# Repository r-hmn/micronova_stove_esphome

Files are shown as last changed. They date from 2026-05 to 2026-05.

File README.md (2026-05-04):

# micronova_stove_esphome
Three sub-projects for connecting a home automation system to ARTEL IDRO15 PelletStove.
1. Kicad PCB for 'ESP32 mini D1'.
2. Arduino-code for reading all RAM- and EEPROM-registers easily.
3. ESPHOME-yaml for connecting the PelletStove to e.g. Home Assistent or OpenHAB.

## Contained projects:

### 1) Kicad `stove-reader-pcb`
A Kicad project for PCB to fit an 'ESP32 mini D1' to communicate with a PelletStove having a MicroNova compatible serial interface.

The PCB has JST-XH2.54 connectors for
- 2x I2C devices
- 2x external DSB18B20 temperature sensors
- 1x for power conversion
- 1x pelletstove serial

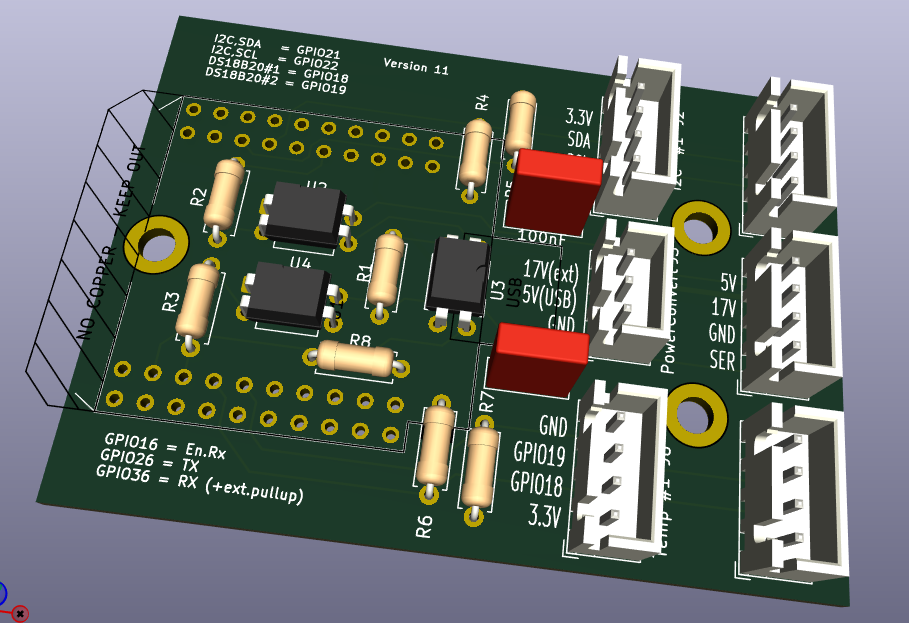
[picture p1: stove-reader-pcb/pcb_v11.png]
PCB


### 2) Arduino `stove-ram-reader`
I created it to find the correct address of the Fume-Temperature address for my stove type.

Works in combination with the PCB.
Code is for ArduinoIDE 2.x to program an 'ESP32 mini D1'.
Program to interrogate the RAM and EEPROM registers and publishes it via its webserver.
Its address is published via mDNS as `esp32.local`
Webserver can be accessed at http://esp32.local/

Uses a version of:
- `micronova_stove.h` code from https://github.com/eni23/micronova-controller
- `micronova_stove.cpp` code from https://github.com/eni23/micronova-controller

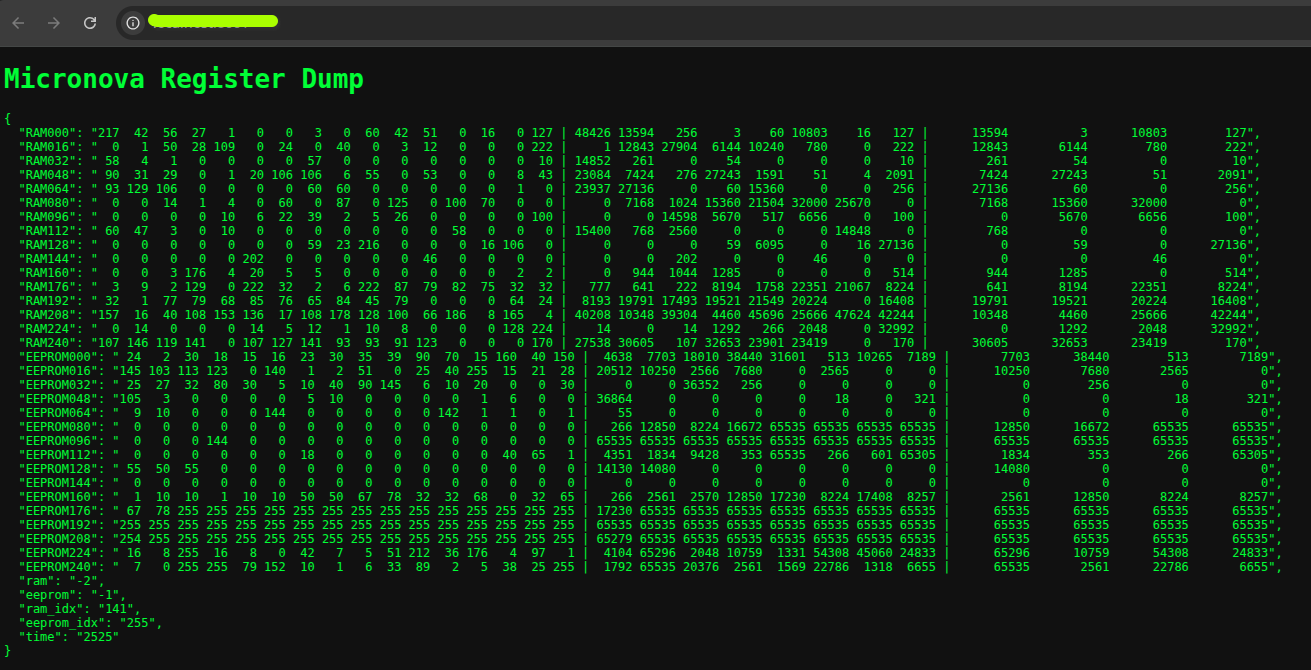
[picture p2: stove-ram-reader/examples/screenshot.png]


### 3) ESPHOME yaml
Works in combination with the PCB.

YAML which interfaces with 
- OLED screen for local readout (i2c OLED 128x32).
- Pellet level sensor (i2c VL53L0X time-of-flight infrared distance sensor).
- External temperature sensors (In below image the DSB18B20's are not connected).

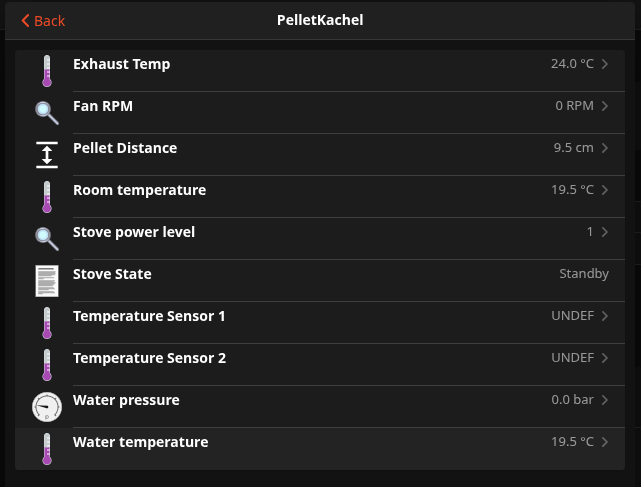
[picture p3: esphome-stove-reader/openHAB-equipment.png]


## Related info:
- https://github.com/eni23/micronova-controller
- https://esphome.io/components/micronova/

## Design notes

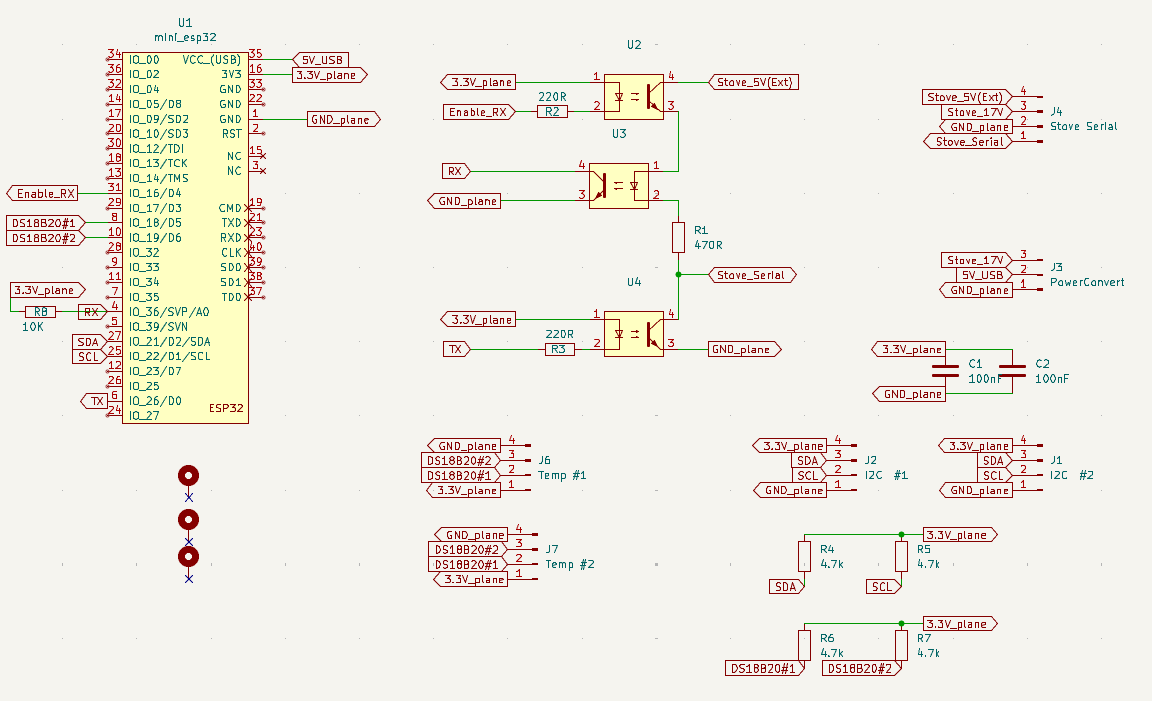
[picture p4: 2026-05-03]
stove-reader-pcb/logic_v11.png

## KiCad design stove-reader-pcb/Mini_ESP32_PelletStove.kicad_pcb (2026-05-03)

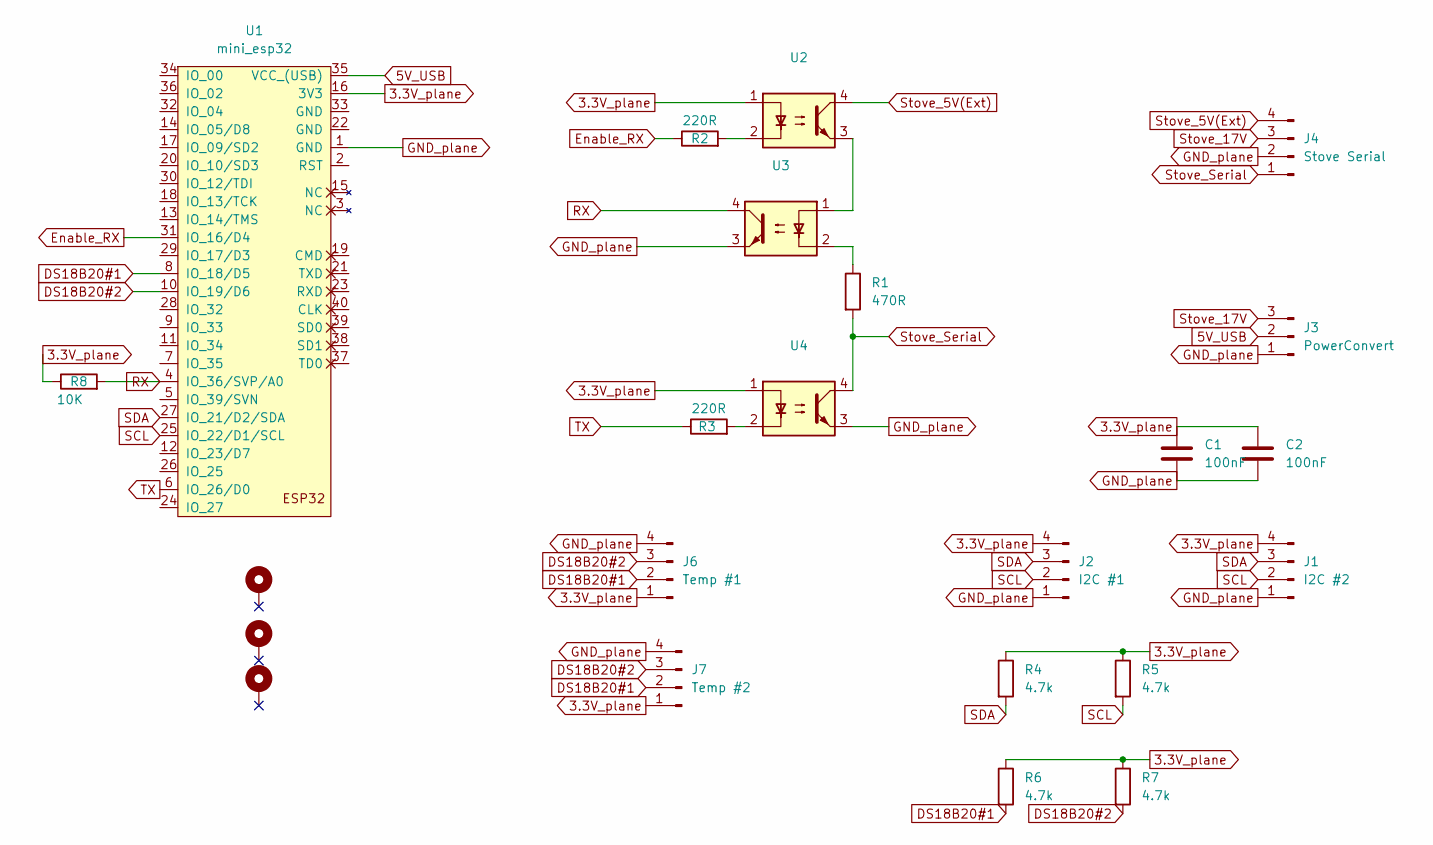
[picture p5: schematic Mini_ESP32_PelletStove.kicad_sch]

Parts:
C1, C2: 100nF; C_Rect_L7.0mm_W2.5mm_P5.00mm
H1, H2, H3: MountingHole_Pad; MountingHole_3.2mm_M3_DIN965_Pad
J1: I2C #2; JST_XH_B4B-XH-A_1x04_P2.50mm_Vertical
J2: I2C #1; JST_XH_B4B-XH-A_1x04_P2.50mm_Vertical
J3: PowerConvert; JST_XH_B3B-XH-A_1x03_P2.50mm_Vertical
J4: Stove Serial; JST_XH_B4B-XH-A_1x04_P2.50mm_Vertical
J6: Temp #1; JST_XH_B4B-XH-A_1x04_P2.50mm_Vertical
J7: Temp #2; JST_XH_B4B-XH-A_1x04_P2.50mm_Vertical
R1: 470R; R_Axial_DIN0207_L6.3mm_D2.5mm_P7.62mm_Horizontal
R2, R3: 220R; R_Axial_DIN0207_L6.3mm_D2.5mm_P7.62mm_Horizontal
R4, R5, R6, R7: 4.7k; R_Axial_DIN0207_L6.3mm_D2.5mm_P7.62mm_Horizontal
R8: 10K; R_Axial_DIN0207_L6.3mm_D2.5mm_P7.62mm_Horizontal
U1: mini_esp32; ESP32_mini-HAT
U2, U3, U4: SFH617A-4X006; DIP-4_W7.62mm

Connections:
3.3V_plane: C1.1, C2.1, J1.4, J2.4, J6.1, J7.1, R4.1, R5.1, R6.1, R7.1, R8.1, U1.16 (3V3), U2.1, U4.1
5V_USB: J3.2, U1.35 (VCC_(USB))
DS18B20#1: J6.2, J7.2, R6.2, U1.8 (IO_18/D5)
DS18B20#2: J6.3, J7.3, R7.2, U1.10 (IO_19/D6)
Enable_RX: R2.1, U1.31 (IO_16/D4)
GND_plane: C1.2, C2.2, J1.1, J2.1, J3.1, J4.2, J6.4, J7.4, U1.1 (GND), U3.3, U4.3
unnamed: R1.1, U3.2
unnamed: R2.2, U2.2
unnamed: R3.2, U4.2
unnamed: U2.3, U3.1
RX: R8.2, U1.4 (IO_36/SVP/A0), U3.4
SCL: J1.2, J2.2, R5.2, U1.25 (IO_22/D1/SCL)
SDA: J1.3, J2.3, R4.2, U1.27 (IO_21/D2/SDA)
Stove_5V(Ext): J4.4, U2.4
Stove_17V: J3.3, J4.3
Stove_Serial: J4.1, R1.2, U4.4
TX: R3.1, U1.6 (IO_26/D0)

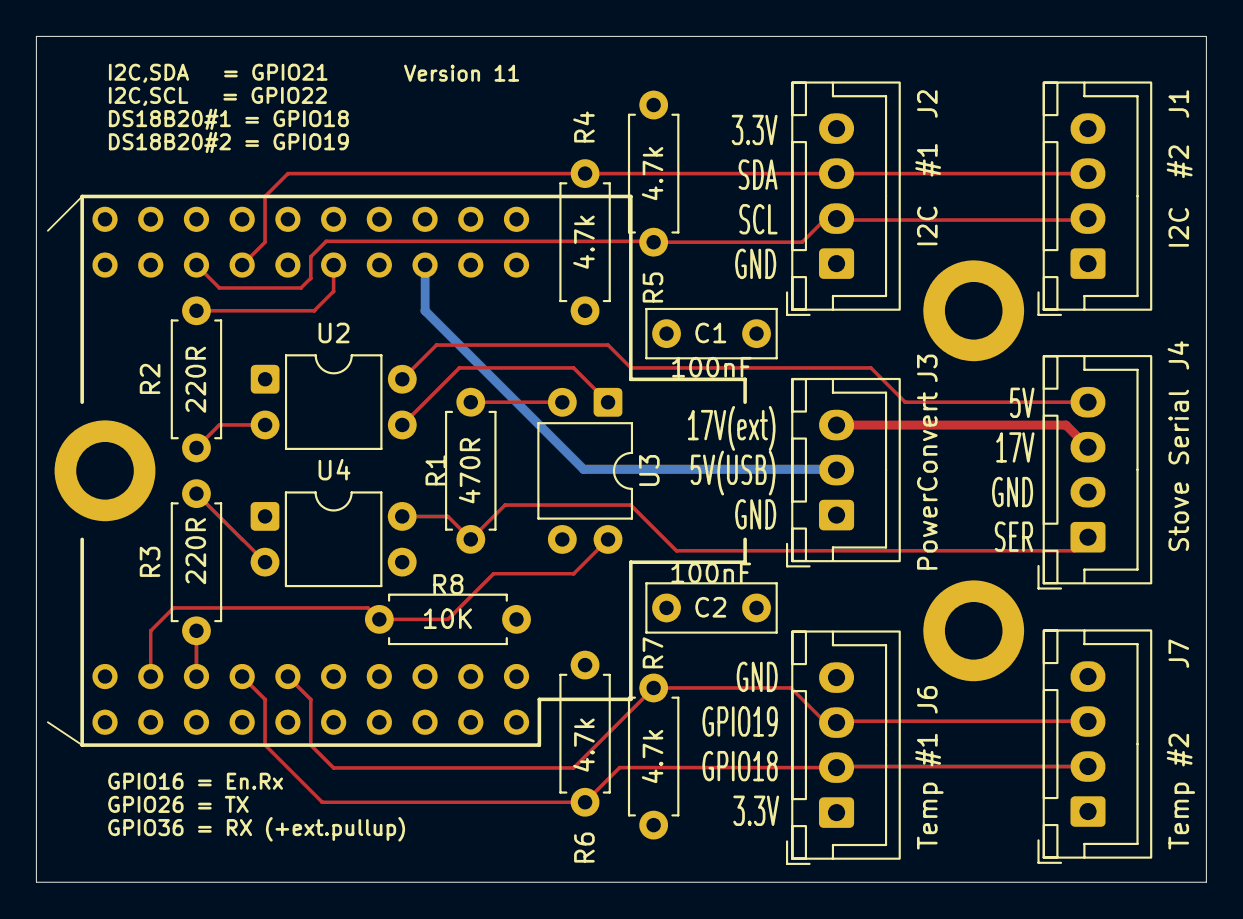
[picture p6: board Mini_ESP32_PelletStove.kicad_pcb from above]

Board: 4 copper layers, 65.0 x 47.0 mm, 23 parts (0 on the bottom side), 17 nets.

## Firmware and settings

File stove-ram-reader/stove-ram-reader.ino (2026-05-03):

/*
Uses libraries:

'ESP Async WebServer' by ESP32Async
https://github.com/ESP32Async/ESPAsyncWebServer

'Async TCP' by ESP32Async
https://github.com/ESP32Async/AsyncTCP

Starts webserver at port 80.
Exposes IP via mDNS address 'esp32.local'

Use:
Main page: http://esp32.local/ 

    Http parameters:
    - http://esp32.local/?ram
    Only updates the ram registers

    - http://esp32.local/?ram=[0-255]
    Only updates a single ram register

    - http://esp32.local/?eeprom
    Only updates the eeprom registers

    - http://esp32.local/?eeprom=[0-255]
    Only updates a single eeprom register

Json data: http://esp32.local/dump   

*/
#include <WiFi.h>
#include <ESPmDNS.h>
#include <ESPAsyncWebServer.h>
#include "micronova_stove.h"
#include "arduino_secrets.h"


// ===== WIFI CONFIG =====
const char* ssid = SECRET_wifi_ssid;
const char* password = SECRET_wifi_password;

// ===== PINS =====
#define RX_PIN 16
#define TX_PIN 26
#define RX_ENABLE_PIN 36

// ===== OBJECTS =====
MicronovaStove stove(RX_PIN, TX_PIN, RX_ENABLE_PIN);
AsyncWebServer server(80);

// ===== CACHE =====
String cachedJson = "{}";
unsigned long lastUpdate = 0;
const int updateInterval = 1000; // ms

unsigned long lastUpdate2 = 0;
const int updateInterval2 = 1000; // ms

uint8_t ram[256];
uint8_t eeprom[256];

uint16_t ram_16[256/2];
uint16_t eeprom_16[256/2];

uint16_t ram_32[256/4];
uint16_t eeprom_32[256/4];

char buf[8000];

int read_ram_register = -1;
int read_eeprom_register = -1;

// ===== HTML PAGE =====
const char htmlPage[] PROGMEM = R"rawliteral(
<!DOCTYPE html>
<html>
<head>
  <title>Micronova Monitor</title>
  <style>
    body { font-family: monospace; background:#111; color:#0f0; }
    pre { font-size: 12px; }
  </style>
</head>
<body>
<h1>Micronova Register Dump</h1>
<pre id="out">Loading...</pre>

<script>
async function load() {
  try {
    let res = await fetch('/dump');
    let data = await res.json();
    document.getElementById('out').textContent =
      JSON.stringify(data, null, 2);
  } catch(e) {
    console.error(e);
    document.getElementById('out').textContent = "Error loading data";
  }
}
setInterval(load, 1000);
load();
</script>

</body>
</html>
)rawliteral";

// ===== READ FUNCTIONS =====
uint8_t readRam(uint8_t addr) {
    stove.read_ram(addr);
    delay(10); // critical for stability
    return stove.last_read_value;
}

uint8_t readEeprom(uint8_t addr) {
    stove.read_eeprom(addr);
    delay(10);
    return stove.last_read_value;
}

// ===== DUMP FUNCTION =====

void readAll() {

    // Read
    Serial.print("ram..");
    if (read_ram_register == -1) { 
        if (read_eeprom_register == -1) {  // only of no special register is requested from both RAM or EEPROM
            for (int i = 0; i < sizeof(ram); i++) {
                ram[i] = readRam(i);
            }
        }
    } else {
        ram[read_ram_register] = readRam(read_ram_register);
    }

    Serial.print("eeprom..");
    if (read_eeprom_register == -1) { 
        if (read_ram_register == -1) {  // only of no special register is requested from both RAM or EEPROM
            for (int i = 0; i < sizeof(eeprom); i++) {
                eeprom[i] = readEeprom(i);
            }
        }
    } else {
        eeprom[read_eeprom_register] = readEeprom(read_eeprom_register);
    }

    // Copy
    for (int i = 0; i < sizeof(ram); i+=2) {
        ram_16[i/2] = ((uint16_t)ram[i]<<16) | ram[i+1];
    }
    for (int i = 0; i < sizeof(eeprom); i+=2) {
        eeprom_16[i/2] = ((uint16_t)eeprom[i]<<16) | eeprom[i+1];
    }

    // Copy
    for (int i = 0; i < sizeof(ram_16); i+=2) {
        ram_32[i/4] = ((uint32_t)ram_16[i]<<32) | ram_16[i+1];
    }
    for (int i = 0; i < sizeof(eeprom_16); i+=2) {
        eeprom_32[i/4] = ((uint16_t)eeprom_16[i]<<32) | eeprom_16[i+1];
    }

}


void dumpRegistersOneLine(char* out) {

    out += sprintf(out, "{\n");
    for (size_t i = 0; i < sizeof(ram)-1; i += 16) {

        out += sprintf(out,
            "\"RAM%03u\":\""
            "%3u %3u %3u %3u %3u %3u %3u %3u %3u %3u %3u %3u %3u %3u %3u %3u | "
            "%5u %5u %5u %5u %5u %5u %5u %5u | "
            "%10u %10u %10u %10u\",\n",
            i,
            ram[i+0], ram[i+1], ram[i+2], ram[i+3],
            ram[i+4], ram[i+5], ram[i+6], ram[i+7],
            ram[i+8], ram[i+9], ram[i+10], ram[i+11],
            ram[i+12], ram[i+13], ram[i+14], ram[i+15],

            ram_16[i/2 + 0], ram_16[i/2 + 1], ram_16[i/2 + 2], ram_16[i/2 + 3],
            ram_16[i/2 + 4], ram_16[i/2 + 5], ram_16[i/2 + 6], ram_16[i/2 + 7],

            ram_32[i/4 + 0], ram_32[i/4 + 1], ram_32[i/4 + 2], ram_32[i/4 + 3]
        );
    }

    for (size_t i = 0; i < sizeof(ram)-1; i += 16) {

        out += sprintf(out,
            "\"EEPROM%03u\":\""
            "%3u %3u %3u %3u %3u %3u %3u %3u %3u %3u %3u %3u %3u %3u %3u %3u | "
            "%5u %5u %5u %5u %5u %5u %5u %5u | "
            "%10u %10u %10u %10u\",\n",
            i,
            eeprom[i+0], eeprom[i+1], eeprom[i+2], eeprom[i+3],
            eeprom[i+4], eeprom[i+5], eeprom[i+6], eeprom[i+7],
            eeprom[i+8], eeprom[i+9], eeprom[i+10], eeprom[i+11],
            eeprom[i+12], eeprom[i+13], eeprom[i+14], eeprom[i+15],

            eeprom_16[i/2 + 0], eeprom_16[i/2 + 1], eeprom_16[i/2 + 2], eeprom_16[i/2 + 3],
            eeprom_16[i/2 + 4], eeprom_16[i/2 + 5], eeprom_16[i/2 + 6], eeprom_16[i/2 + 7],

            eeprom_32[i/4 + 0], eeprom_32[i/4 + 1], eeprom_32[i/4 + 2], eeprom_32[i/4 + 3]
        );
    }

    out += sprintf(out, "\"ram\":\"%d\",", read_ram_register);
    out += sprintf(out, "\"eeprom\":\"%d\",", read_eeprom_register);

    out += sprintf(out, "\"time\":\"%d\"\n}", lastUpdate2/1000);

    *out = '\0';   // terminate string
}


// ===== WIFI =====
void setupWiFi() {
    WiFi.begin(ssid, password);
    Serial.print("Connecting");

    while (WiFi.status() != WL_CONNECTED) {
        delay(500);
        Serial.print(".");
    }

    Serial.println("\nConnected!");
    Serial.println(WiFi.localIP());

    if (!MDNS.begin("esp32")) {
        Serial.println("Error starting mDNS");
    } else {
        MDNS.addService("http", "tcp", 80);
        Serial.println("mDNS started: http://esp32.local");
    }

}

// ===== WEB SERVER =====
void setupWeb() {

    server.on("/", HTTP_GET, [](AsyncWebServerRequest *request){

        if (request->hasParam("ram")) {
            String value = request->getParam("ram")->value();
            read_ram_register = value.toInt();
            read_ram_register &= 0xFF;
        } else {
            read_ram_register = -1;
        }

        if (request->hasParam("eeprom")) {
            String value = request->getParam("eeprom")->value();
            read_eeprom_register = value.toInt();
            read_eeprom_register &= 0xFF;
        } else {
            read_eeprom_register = -1;
        }

        request->send_P(200, "text/html", htmlPage);
    });

    server.on("/dump", HTTP_GET, [](AsyncWebServerRequest *request){

        if (millis() - lastUpdate2 > updateInterval2) {
            dumpRegistersOneLine(buf);
            cachedJson = String(buf);

            lastUpdate2 = millis();            
        }

        request->send(200, "application/json", cachedJson);
    });

    server.begin();
}

// ===== SETUP =====
void setup() {
    Serial.begin(115200);

    pinMode(RX_PIN, INPUT);
    pinMode(TX_PIN, OUTPUT);
    pinMode(RX_ENABLE_PIN, OUTPUT);
    stove.init();  // init micronova serial

    setupWiFi();
    setupWeb();
}

// ===== LOOP =====
void loop() {

    // refresh cache every X seconds
    if (millis() - lastUpdate > updateInterval) {
        Serial.println("Updating register dump...");
        readAll();
        Serial.println("..done");

        lastUpdate = millis();
    }
}

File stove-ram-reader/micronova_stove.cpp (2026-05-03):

#include "Arduino.h"
#include "micronova_stove.h"

// Original from: https://github.com/eni23/micronova-controller

/* =================================
 * Changelog
 * =================================
 * 2026-05-01  Changed timing to fit speedup for ARTEL IDRO.
 *             (Used "USB logic analyzer" to see dead-times in communication)
 * 2026-05-03  Added ARTEL addresses
 * =================================*/

#if defined(ESP8266) || defined(USE_SWSERIAL)
  #include <SoftwareSerial.h>
  SoftwareSerial StoveSerial;
#endif

#if defined(ESP32) || defined(USE_HWSERIAL)
  #include <HardwareSerial.h>
  HardwareSerial StoveSerial(1);
#endif


MicronovaStove::MicronovaStove( int rx, int tx, int rx_enable ) {
  pin_rx = rx;
  pin_tx = tx;
  pin_rx_enable = rx_enable;
}


void MicronovaStove::init(){
  StoveSerial.begin( 1200, SERIAL_MODE, pin_rx, pin_tx, false, 256 );
  if (dbg_out) printf("begin stove serial");
  pinMode( pin_rx_enable, OUTPUT );
  digitalWrite( pin_rx_enable, HIGH ); 
}


/* read functions */

void MicronovaStove::enable_rx(){
  if (dbg_out) printf("enable rx\n");
  digitalWrite( pin_rx_enable, LOW );
}


void MicronovaStove::disable_rx(){
  if (dbg_out) printf("disable rx\n");
  digitalWrite( pin_rx_enable, HIGH );
}


void MicronovaStove::flushInput(){
  if (dbg_out) printf("flush serial input\n");
    while (Serial.available()){
      Serial.read();
      if (dbg_out) printf("flush: read 1 extra byte\n");
    }
}



void MicronovaStove::read(uint8_t location, uint8_t addr){
      
  dbg_out=false;

  if (dbg_out){
    printf("read request loc=");
    printf("0x%02x ", location );
    printf(", addr=");
    printf("0x%02x ", addr );
    printf("\n");

  }

      
  StoveSerial.write(location);
  StoveSerial.flush();
  StoveSerial.write(addr);
  StoveSerial.flush();

  enable_rx();
  // the stove needs some time to answer, 120ms seems about the right amount, 110 is too short
  delay(120);

  if (dbg_out) printf("read stove answer\n");

  uint8_t rx_count = 0;
  stove_rx_data[0] = 0x00;
  stove_rx_data[1] = 0x00;
      
  while ( StoveSerial.available() ) {
    if (rx_count>1){
      // TODO: find a better way to do this
      rx_count = 0;
    }
    stove_rx_data[rx_count] = StoveSerial.read();
    if (dbg_out) printf("i=0x%02x data=0x%02x\n",rx_count,stove_rx_data[rx_count]);
    rx_count++;
  }

      
  disable_rx();
  last_read_value = stove_rx_data[1];
  last_read_checksum = stove_rx_data[0];
  last_read_param = last_read_checksum - last_read_value;

  if (last_read_param != addr ){
    if (dbg_out) printf("E: return mismatch\n");
  }
  // TODO: check for error with checksum
}


uint8_t MicronovaStove::read_ram( uint8_t addr ){
  read( STOVE_OFFSET_RAM_READ, addr );
  return last_read_value;
}

uint8_t MicronovaStove::read_eeprom( uint8_t addr ){
  read( STOVE_OFFSET_EEPROM_READ, addr );
  return last_read_value;
}



/* write functions */

void MicronovaStove::write( uint8_t location, uint8_t command, uint8_t data ){
  uint8_t chk = calculate_checksum( location, command, data );
  uint8_t data_to_write[4] = {
    location,
    command,
    data,
    chk
  };
  
  if (dbg_out) printf("write data=");
    
  for ( int i = 0; i < 4; i++ ){
    if (dbg_out) printf("0x%02x ", data_to_write[i] );
    StoveSerial.write( data_to_write[i] );
    delay(1);
  }
    
  if (dbg_out) printf("\n");

}


void MicronovaStove::read_answer(){
  enable_rx();
  delay(120);
  uint8_t rx_count = 0;
  stove_rx_data[0] = 0x00;
  stove_rx_data[1] = 0x00;
      
  while ( StoveSerial.available() ) {
    if (rx_count>1){
      // TODO: find a better way to do this
      rx_count = 0;
    }
    stove_rx_data[rx_count] = StoveSerial.read();
    rx_count++;
  }
  disable_rx();
  last_read_value = stove_rx_data[1];
  last_read_checksum = stove_rx_data[0];
  
}


void MicronovaStove::write_ram( uint8_t command, uint8_t data ){
  write( STOVE_OFFSET_RAM_WRITE, command, data );
}

void MicronovaStove::write_eeprom( uint8_t command, uint8_t data ){
  write( STOVE_OFFSET_EEPROM_WRITE, command, data);
}


byte MicronovaStove::calculate_checksum( uint8_t dest, uint8_t addr, uint8_t val ){
  uint8_t checksum = 0;
  checksum = dest+addr+val;
  if ( checksum >= 256 ){
    checksum = checksum - 256;
  }
  return (uint8_t)checksum;
}




/* Abstraction helper functions */
uint8_t MicronovaStove::get_state(){
  read_ram(STOVE_ADDR_STATE);
  return last_read_value;
}

void MicronovaStove::on(){
  write_ram(STOVE_ADDR_STATE, STOVE_STATE_TURN_ON);
}


void MicronovaStove::off(){
  simulate_infrared(STOVE_IR_POWER, 15);
}


float MicronovaStove::get_ambient_temp(){
  read_ram(STOVE_ADDR_AMBIENT_TEMP);
  return (float) last_read_value / 2;
}


uint8_t MicronovaStove::get_fumes_temp(){
  read_ram(STOVE_ADDR_FUMES_TEMP);
  return last_read_value;
}


uint8_t MicronovaStove::get_power(){
  read_ram(STOVE_ADDR_POWER_EEPROM);
  return last_read_value;
}


uint16_t MicronovaStove::get_fumes_fan_speed(){
  read_ram(STOVE_ADDR_FUMES_SPEED);
  return (uint16_t) last_read_value*10;
}


void MicronovaStove::set_power(uint8_t power_level){
  if (power_level > 4){
    power_level = 4;
  }
  // TODO: check if we really need to do this twice
  write_eeprom(STOVE_ADDR_POWER_EEPROM, power_level);
  write_ram(STOVE_ADDR_POWER_RAM, power_level);
}


void MicronovaStove::set_thermostat(uint8_t temperature){
  if (temperature > 32){
    temperature = 32;
  }
  write_eeprom(STOVE_ADDR_THERMOSTAT, temperature);
}

void MicronovaStove::simulate_infrared(uint8_t data, uint8_t repetitions){
  for (uint8_t i=0; i<repetitions; i++){
    write_ram(STOVE_ADDR_IRCOMMAND, data);
    delay(80);
  }
}
